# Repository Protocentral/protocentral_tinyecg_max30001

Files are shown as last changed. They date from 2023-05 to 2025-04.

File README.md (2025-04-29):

# ProtoCentral tinyECG MAX30001G ECG & Respiration monitoring module



## Don't have one? [Buy it here](https://protocentral.com/product/protocentral-tinyecg-max30001-ecg-respiration-module-for-qt-py-xiao/)

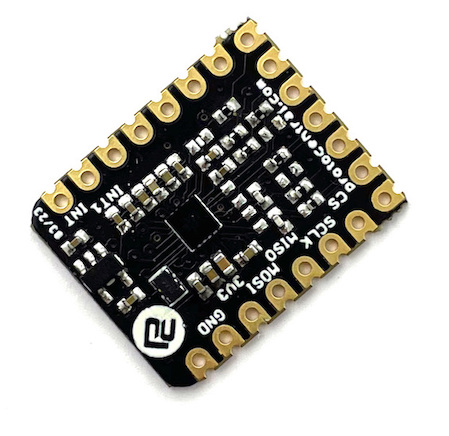
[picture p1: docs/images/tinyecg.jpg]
tinyECG MAX30001


ProtoCentral tinyECG MAX30001G ECG & Respiration monitoring module is a tiny module based on the Analog Devices MAX30001 ECG and Respiration sensor. It is a single lead ECG and Respiration sensor with a built-in amplifier, front-end and ADC. It can be used to measure ECG and Respiration signals from the human body. 

The form factor of the module is designed to fit the [Adafruit QT Py](https://www.adafruit.com/category/595) or[Seeed Studio XIAO](https://wiki.seeedstudio.com/Seeeduino-XIAO/) series of microcontroller boards. These boards offers a tiny form factor with a built-in USB port and a battery connector and are based on your choice of a multitude of microcontrollers . Coupled with one of these boards, you can build a tiny wearable ECG and Respiration monitoring device.

## Hardware Setup

Connection with the Adafruit QT PY ESP32-C3 is as follows:

|Tiny ECG pin label| Adafruit QT PY ESP32-C3 Connection |Pin Function |
|--- |:---:|---:|
| MISO | MISO |  Slave out| 
| MOSI | MOSI |  Slave in |
| SCK | SCK |  Serial clock |
| CS0 | 6 |  Slave select|
| FCLK | NC |  External clock |
| INT1 | A0 |  Interrupt |
| INT2 | NC |  Interrupt |
| Vcc | +5V | Power Supply |
| GND | GND | GND

# Visualizing Output

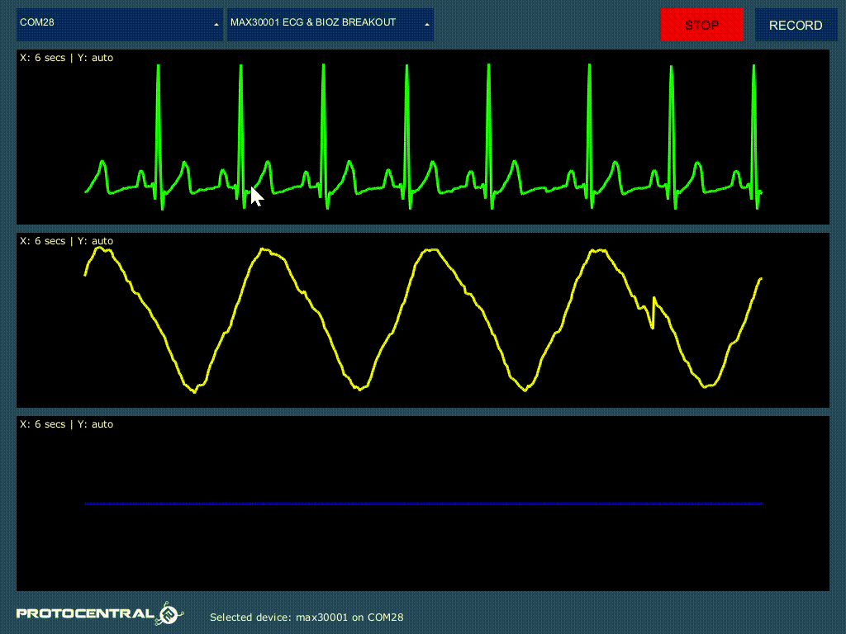
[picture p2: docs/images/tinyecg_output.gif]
openview output


## For further details, refer [the documentation on TinyECG module](https://docs.protocentral.com/getting-started-with-tinyECG/)

License Information
===================

License

This product is open source! Both, our hardware and software are open source and licensed under the following licenses:

Hardware
---------

**All hardware is released under the [CERN-OHL-P v2](https://ohwr.org/cern_ohl_p_v2.txt)** license.

Copyright CERN 2020.

This source describes Open Hardware and is licensed under the CERN-OHL-P v2.

You may redistribute and modify this documentation and make products
using it under the terms of the CERN-OHL-P v2 (https:/cern.ch/cern-ohl).
This documentation is distributed WITHOUT ANY EXPRESS OR IMPLIED
WARRANTY, INCLUDING OF MERCHANTABILITY, SATISFACTORY QUALITY
AND FITNESS FOR A PARTICULAR PURPOSE. Please see the CERN-OHL-P v2
for applicable conditions

Software
--------

**All software is released under the MIT License(http://opensource.org/licenses/MIT).**

THE SOFTWARE IS PROVIDED "AS IS", WITHOUT WARRANTY OF ANY KIND, EXPRESS OR IMPLIED, INCLUDING BUT NOT LIMITED TO THE WARRANTIES OF MERCHANTABILITY, FITNESS FOR A PARTICULAR PURPOSE AND NONINFRINGEMENT. IN NO EVENT SHALL THE AUTHORS OR COPYRIGHT HOLDERS BE LIABLE FOR ANY CLAIM, DAMAGES OR OTHER LIABILITY, WHETHER IN AN ACTION OF CONTRACT, TORT OR OTHERWISE, ARISING FROM, OUT OF OR IN CONNECTION WITH THE SOFTWARE OR THE USE OR OTHER DEALINGS IN THE SOFTWARE.

Documentation
-------------
**All documentation is released under [Creative Commons Share-alike 4.0 International](http://creativecommons.org/licenses/by-sa/4.0/).**


You are free to:

* Share — copy and redistribute the material in any medium or format
* Adapt — remix, transform, and build upon the material for any purpose, even commercially.
The licensor cannot revoke these freedoms as long as you follow the license terms.

Under the following terms:

* Attribution — You must give appropriate credit, provide a link to the license, and indicate if changes were made. You may do so in any reasonable manner, but not in any way that suggests the licensor endorses you or your use.
* ShareAlike — If you remix, transform, or build upon the material, you must distribute your contributions under the same license as the original.

Please check [*LICENSE.md*](LICENSE.md) for detailed license descriptions.

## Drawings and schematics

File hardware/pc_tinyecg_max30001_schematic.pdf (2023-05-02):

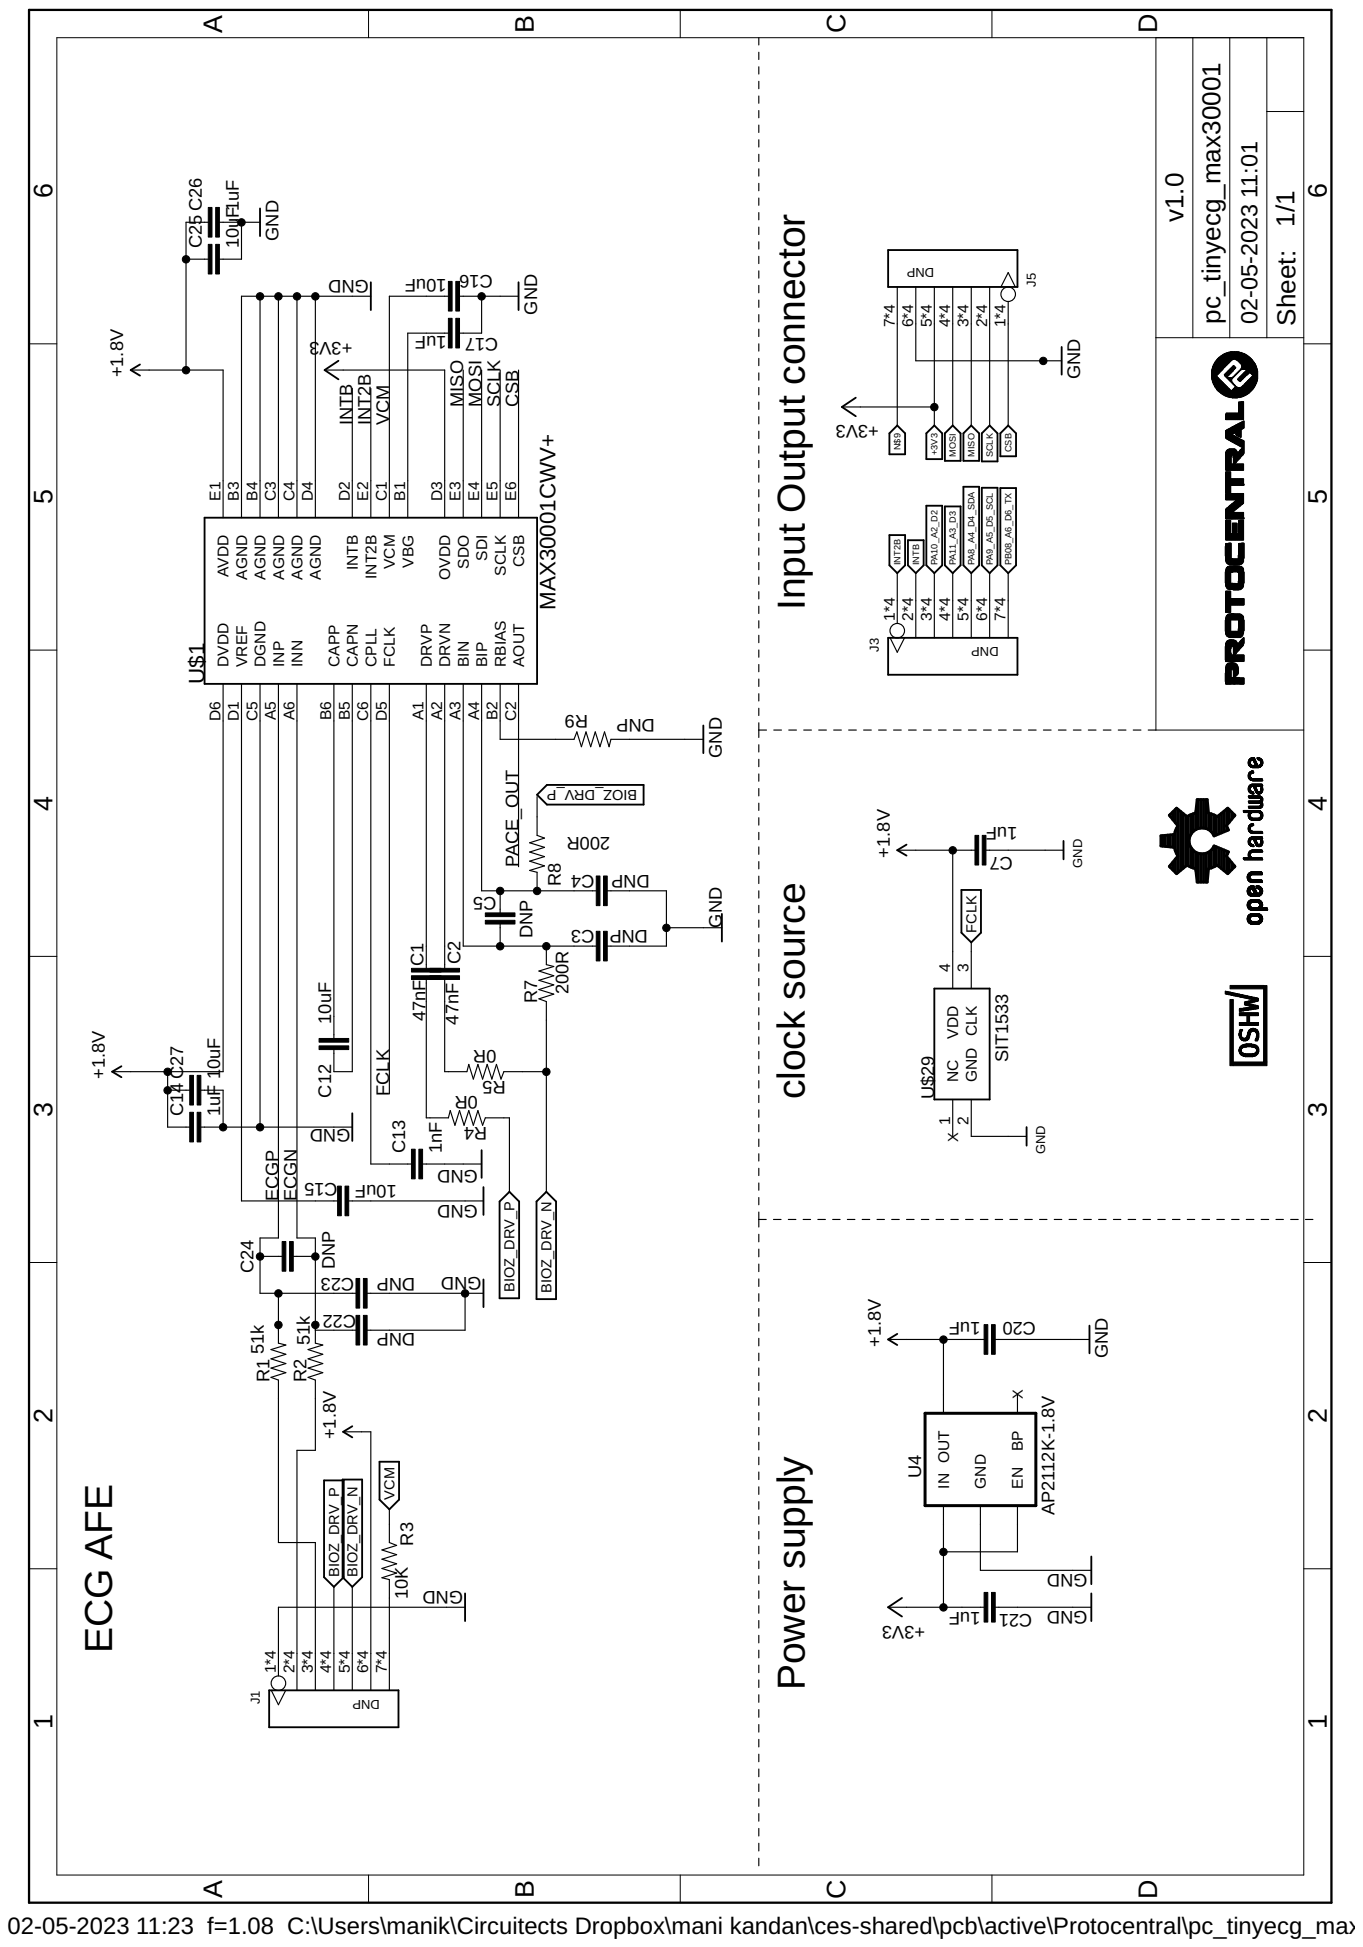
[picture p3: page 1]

02-05-2023 11:23 f=1.08 C:\Users\manik\Circuitects Dropbox\mani kandan\ces-shared\pcb\active\Protocentral\pc_tinyecg_max30001\pc_tinyecg_max30001.sch (Sheet: 1/1)

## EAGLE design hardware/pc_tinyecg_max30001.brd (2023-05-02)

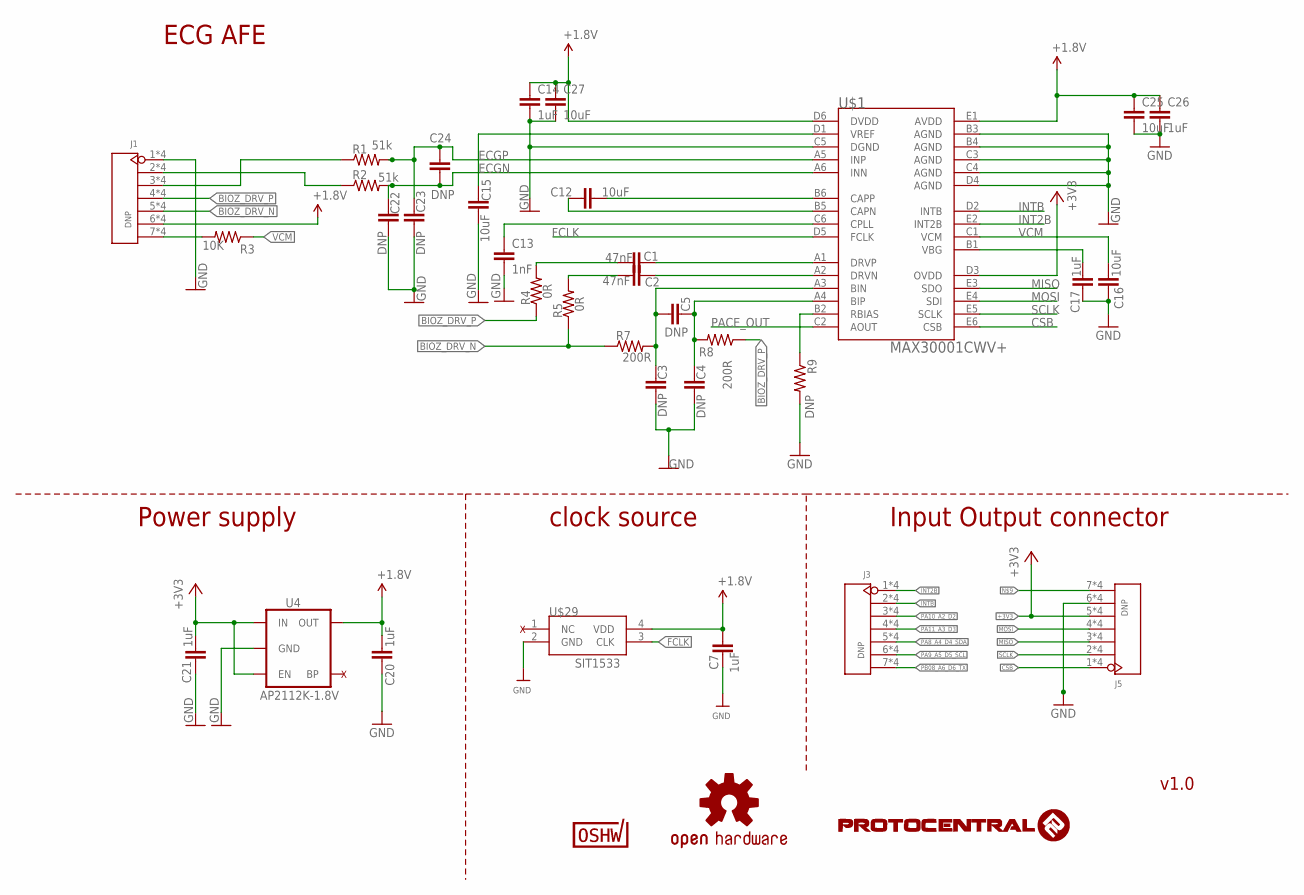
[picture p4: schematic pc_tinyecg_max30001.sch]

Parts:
C1, C2: 47nF; C0402
C3, C4, C5, C22, C23, C24: DNP; C0402
C7, C14, C17, C20, C21, C26: 1uF; C0402
C12, C15, C16, C25, C27: 10uF; C0402
C13: 1nF; C0402
J1, J3, J5: DNP; H7-HALF-HOLE-2.54
R1, R2: 51k; 0402-RES
R3: 10K; 0402-RES
R4, R5: 0R; 0402-RES
R7, R8: 200R; 0402-RES
R9: DNP; 0402-RES
U4: AP2112K-1.8V; SOT23-5
U$1: MAX30001CWV+; 30WLP
U$14: OSHW-LOGOM; OSHW-LOGO-M
U$29: SIT1533
U$35: CERT-SMALL; CERT-SMALL-SILK

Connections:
+1.8V: C7.2, C14.1, C20.2, C25.1, C26.1, C27.1, J1.6, J1.18 (6), J1.P$6 (6), J1.P$9 (6), U4.5 (OUT), U$1.D6 (DVDD), U$1.E1 (AVDD), U$29.4 (VDD)
+3V3: C21.2, J5.5, J5.17 (5), J5.P$5 (5), J5.P$10 (5), U4.1 (IN), U4.3 (EN), U$1.D3 (OVDD)
BIOZ_DRV_N: J1.5, J1.17 (5), J1.P$5 (5), J1.P$10 (5), R5.1, R7.1
BIOZ_DRV_P: J1.4, J1.16 (4), J1.P$4 (4), J1.P$11 (4), R4.1, R8.1
CSB: J5.1, J5.13 (1), J5.P$1 (1), J5.P$14 (1), U$1.E6 (CSB)
ECGN: C22.1, C24.2, R2.2, U$1.A6 (INN)
ECGN1: J1.2, J1.14 (2), J1.P$2 (2), J1.P$13 (2), R2.1
ECGP: C23.1, C24.1, R1.2, U$1.A5 (INP)
ECGP1: J1.3, J1.15 (3), J1.P$3 (3), J1.P$12 (3), R1.1
FCLK: U$1.D5 (FCLK), U$29.3 (CLK)
GND: C3.2, C4.2, C7.1, C13.2, C14.2, C15.2, C16.2, C17.2, C20.1, C21.1, C22.2, C23.2, C25.2, C26.2, C27.2, J1.1, J1.13 (1), J1.P$1 (1), J1.P$14 (1), J5.6, J5.18 (6), J5.P$6 (6), J5.P$9 (6), R9.2, U4.2 (GND), U$1.B3 (AGND), U$1.B4 (AGND), U$1.C3 (AGND), U$1.C4 (AGND), U$1.C5 (DGND), U$1.D4 (AGND), U$29.2 (GND)
INT2B: J3.1, J3.13 (1), J3.P$1 (1), J3.P$14 (1), U$1.E2 (INT2B)
INTB: J3.2, J3.14 (2), J3.P$2 (2), J3.P$13 (2), U$1.D2 (INTB)
MISO: J5.3, J5.15 (3), J5.P$3 (3), J5.P$12 (3), U$1.E3 (SDO)
MOSI: J5.4, J5.16 (4), J5.P$4 (4), J5.P$11 (4), U$1.E4 (SDI)
unnamed: C12.1, U$1.B6 (CAPP)
unnamed: C1.2, U$1.A1 (DRVP)
unnamed: C2.1, R5.2
unnamed: C2.2, U$1.A2 (DRVN)
unnamed: C3.1, C5.1, R7.2, U$1.A3 (BIN)
unnamed: C4.1, C5.2, R8.2, U$1.A4 (BIP)
unnamed: R9.1, U$1.B2 (RBIAS)
unnamed: J1.7, J1.19 (7), J1.P$7 (7), J1.P$8 (7), R3.2
unnamed: J5.7, J5.19 (7), J5.P$7 (7), J5.P$8 (7)
unnamed: C13.1, U$1.C6 (CPLL)
unnamed: C1.1, R4.2
unnamed: C12.2, U$1.B5 (CAPN)
unnamed: C15.1, U$1.D1 (VREF)
unnamed: C17.1, U$1.B1 (VBG)
PA8_A4_D4_SDA: J3.5, J3.17 (5), J3.P$5 (5), J3.P$10 (5)
PA9_A5_D5_SCL: J3.6, J3.18 (6), J3.P$6 (6), J3.P$9 (6)
PA10_A2_D2: J3.3, J3.15 (3), J3.P$3 (3), J3.P$12 (3)
PA11_A3_D3: J3.4, J3.16 (4), J3.P$4 (4), J3.P$11 (4)
PACE_OUT: U$1.C2 (AOUT)
PB08_A6_D6_TX: J3.7, J3.19 (7), J3.P$7 (7), J3.P$8 (7)
SCLK: J5.2, J5.14 (2), J5.P$2 (2), J5.P$13 (2), U$1.E5 (SCLK)
VCM: C16.1, R3.1, U$1.C1 (VCM)

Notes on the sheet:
v1.0
Power supply
clock source
Input Output connector
ECG AFE

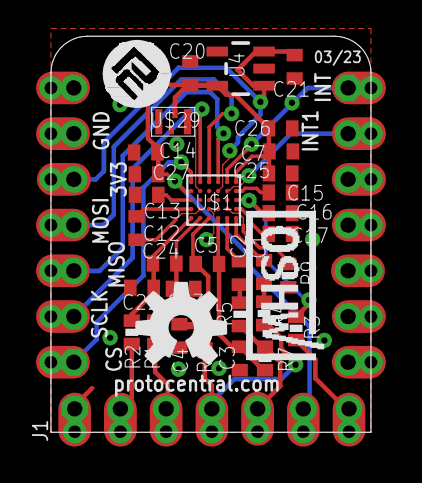
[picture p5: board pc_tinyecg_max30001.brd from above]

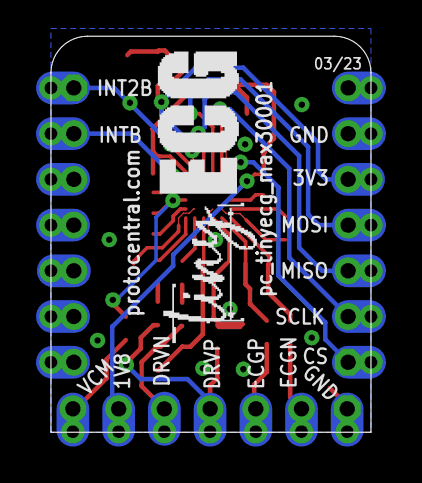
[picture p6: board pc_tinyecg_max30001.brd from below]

Board: 2 copper layers, 17.8 x 22.0 mm, 38 parts (3 on the bottom side), 36 nets.

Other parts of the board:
U$4: TNYECG_LOGO
U$5: PCROUNDLOGO

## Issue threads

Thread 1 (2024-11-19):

INT2B Pin Sorts to GND

prashant3285, 2024-11-19:
Had spent a lot of time configuring the EN_INT2, but the INT2B pin failed to respond.
Finally, it seems that the board has a design defect.
INT2B is sorted to GND due to an unnecessary via (via marked green comes to top and connects to ground plane)
Tested with the good old multimeter
Hope this is fixed in the next batch
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

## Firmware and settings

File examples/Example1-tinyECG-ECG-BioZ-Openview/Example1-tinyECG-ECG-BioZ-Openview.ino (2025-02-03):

//////////////////////////////////////////////////////////////////////////////////////////
//
//    Demo code for the TinyECG breakout board
//
//    This example plots the ECG through serial UART on openview processing GUI.
//    GUI URL: https://github.com/Protocentral/protocentral_openview.git
//
//    Arduino connections:
//
//  |Tiny ECG pin label| Pin Function         |Adafruit QT PY ESP32-C3 Connection|
//  |----------------- |:--------------------:|---------------------------------:|
//  | MISO             | Slave Out            |  MISO                            |
//  | MOSI             | Slave In             |  MOSI                            |
//  | SCLK             | Serial Clock         |  SCK                             |
//  | CS               | Chip Select          |  6                               |
//  | 3V3              | Digital VDD          |  3V                              |
//  | GND              | Digital Gnd          |  Gnd                             | 
//  | FCLK             | 32K CLOCK            |  -                               |
//  | INTB             | Interrupt1           |  A0                              | 
//  | INT2B            | Interrupt2           |  -                               | 
//
//    This software is licensed under the MIT License(http://opensource.org/licenses/MIT).
//
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
//   For information on how to use, visit https://github.com/Protocentral/protocentral_max30001
//
/////////////////////////////////////////////////////////////////////////////////////////

#include <SPI.h>
#include "protocentral_max30001.h"

#define MAX30001_CS_PIN 20 
#define MAX30001_MISO_PIN 8
#define MAX30001_MOSI_PIN 7
#define MAX30001_SCK_PIN 10
#define MAX30001_DELAY_SAMPLES 8 // Time between consecutive samples

#define CES_CMDIF_PKT_START_1 0x0A
#define CES_CMDIF_PKT_START_2 0xFA
#define CES_CMDIF_TYPE_DATA 0x02
#define CES_CMDIF_PKT_STOP 0x0B
#define DATA_LEN 0x0C
#define ZERO 0

volatile char DataPacket[DATA_LEN];
const char DataPacketFooter[2] = {ZERO, CES_CMDIF_PKT_STOP};
const char DataPacketHeader[5] = {CES_CMDIF_PKT_START_1, CES_CMDIF_PKT_START_2, DATA_LEN, ZERO, CES_CMDIF_TYPE_DATA};

signed long ecg_data;
signed long bioz_data;
bool BioZSkipSample = false;

MAX30001 max30001(MAX30001_CS_PIN);

void sendData(signed long ecg_sample, signed long bioz_sample, bool _bioZSkipSample)
{

  DataPacket[0] = ecg_sample;
  DataPacket[1] = ecg_sample >> 8;
  DataPacket[2] = ecg_sample >> 16;
  DataPacket[3] = ecg_sample >> 24;

  DataPacket[4] = bioz_sample;
  DataPacket[5] = bioz_sample >> 8;
  DataPacket[6] = bioz_sample >> 16;
  DataPacket[7] = bioz_sample >> 24;

  if (_bioZSkipSample == false)
  {
    DataPacket[8] = 0x00;
  }
  else
  {
    DataPacket[8] = 0xFF;
  }

  DataPacket[9] = 0x00; // max30001.heartRate >> 8;
  DataPacket[10] = 0x00;
  DataPacket[11] = 0x00;

  // Send packet header (in ProtoCentral OpenView format)
  for (int i = 0; i < 5; i++)
  {
    Serial.write(DataPacketHeader[i]);
  }

  // Send the data payload
  for (int i = 0; i < DATA_LEN; i++) // transmit the data
  {
    Serial.write(DataPacket[i]);
  }

  // Send packet footer (in ProtoCentral OpenView format)
  for (int i = 0; i < 2; i++)
  {
    Serial.write(DataPacketFooter[i]);
  }
}


void setup()
{
  Serial.begin(57600); // Serial begin
   
  SPI.begin(MAX30001_SCK_PIN,MAX30001_MISO_PIN,MAX30001_MOSI_PIN,MAX30001_CS_PIN);

  pinMode(MAX30001_CS_PIN, OUTPUT);
  digitalWrite(MAX30001_CS_PIN, HIGH);

  bool ret = max30001.max30001ReadInfo();
  if (ret)
  {
    Serial.println("MAX 30001 read ID Success");
  }
  else
  {
    while (!ret)
    {
      // stay here untill the issue is fixed.
      ret = max30001.max30001ReadInfo();
      Serial.println("Failed to read ID, please make sure all the pins are connected");
      delay(5000);
    }
  }

  Serial.println("Initialising the chip ...");
  max30001.BeginECGBioZ(); // initialize MAX30001
}

void loop()
{
  ecg_data = max30001.getECGSamples();
  if (BioZSkipSample == false)
  {
    bioz_data = max30001.getBioZSamples();
    sendData(ecg_data, bioz_data, BioZSkipSample);
    BioZSkipSample = true;
  }
  else
  {
    bioz_data = 0x00;
    sendData(ecg_data, bioz_data, BioZSkipSample);
    BioZSkipSample = false;
  }
  delay(MAX30001_DELAY_SAMPLES);
}

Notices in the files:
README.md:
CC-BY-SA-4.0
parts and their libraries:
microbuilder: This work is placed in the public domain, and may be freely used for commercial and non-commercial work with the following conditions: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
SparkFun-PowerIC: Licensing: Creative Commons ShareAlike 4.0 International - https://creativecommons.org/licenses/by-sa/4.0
